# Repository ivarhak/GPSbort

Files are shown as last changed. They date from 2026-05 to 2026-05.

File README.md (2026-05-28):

Hello reader!

This project was made as part of the Hack Club Macondo hardware event. 
The main idea was that I wanted to familiarize myself with design of RF related applications on PCBs.

The board has the following central components: 
NEO-N9M GPS module 
USB Type-C connector 
MT3608 Boost converter 
ESP32-C3-WROOM 
2 SMA jacks for antennas (LORA and GPS) 
AMS1117-3.3 LDO 
DL-RFM95 LORA transceiver

These components allow the board to recieve its GPS position, do some computation then transmit using built in wifi or bluetooth or even using LORA signal up to 5km!
Useful in scenarios like a missing hiker who needs to tell others where they are, or if you have a rocket thats drifted out of your predicted landing zone and you need to find it.

Screenshot 2026-05-27 at 4 51 59 PM
Screenshot 2026-05-27 at 4 51 49 PM
Screenshot 2026-05-27 at 4 51 35 PM

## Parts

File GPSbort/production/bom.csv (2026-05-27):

Designator | Footprint | Quantity | Value | LCSC Part #
_5, _4, _3, _2, |  | 5
BAT1 | BAT-TH_2P-P14.50_2462 | 1 | 2462 | C3029547
C1, C3, C4 | 1206 | 3 | 22uF
C2, C5, C6, C8, C9 | 1206 | 5 | 10uF
C7 | 1206 | 1 | 0.1uF
D1 | 1206 | 1 | D
L1 | 1206 | 1 | 4.7 uH
R1 | 1206 | 1 | 100K
R2 | 1206 | 1 | 15K
R3 | 1206 | 1 | 1M
R4, R5 | 1206 | 2 | 10K
R6, R7, R9 | 1206 | 3 | 5.1K
R8 | 1206 | 1 | 4.7K
RF1, RF2 | SMA-TH_SMA-KWE902 | 2 | SMA-KWE902 | C914554
SW1 | KEY-SMD_L4.0-W3.0-LS4.9-1 | 1 | HX 3X4X2-2P-1.6N TACTILE SWITCH | C49234124
U1 | GPSM-SMD_24P-L16.0-W12.2-P1.10-BL | 1 | NEO-M9N-00B | C5119087
U2 | BULETM-SMD_ESPRESSIF_ESP32-C3-WROOM-02-N4-4MB | 1 | ESP32-C3-WROOM-02-N4 | C2934560
U3 | LCC-16_L16.0-W16.0-P2.00-TL | 1 | DL-RFM95-915M | C2844473
U4 | SOT-23-6_L2.9-W1.6-P0.95-LS2.8-BL | 1 | MT3608 | C84817
U5 | SOT-223-3_L6.5-W3.4-P2.30-LS7.0-BR | 1 | AMS1117-3.3 | C6186
USB1 | USB-C-SMD_TYPE-C-6PIN-2MD-073 | 1 | TYPE-C 16PIN 2MD(073) | C2765186

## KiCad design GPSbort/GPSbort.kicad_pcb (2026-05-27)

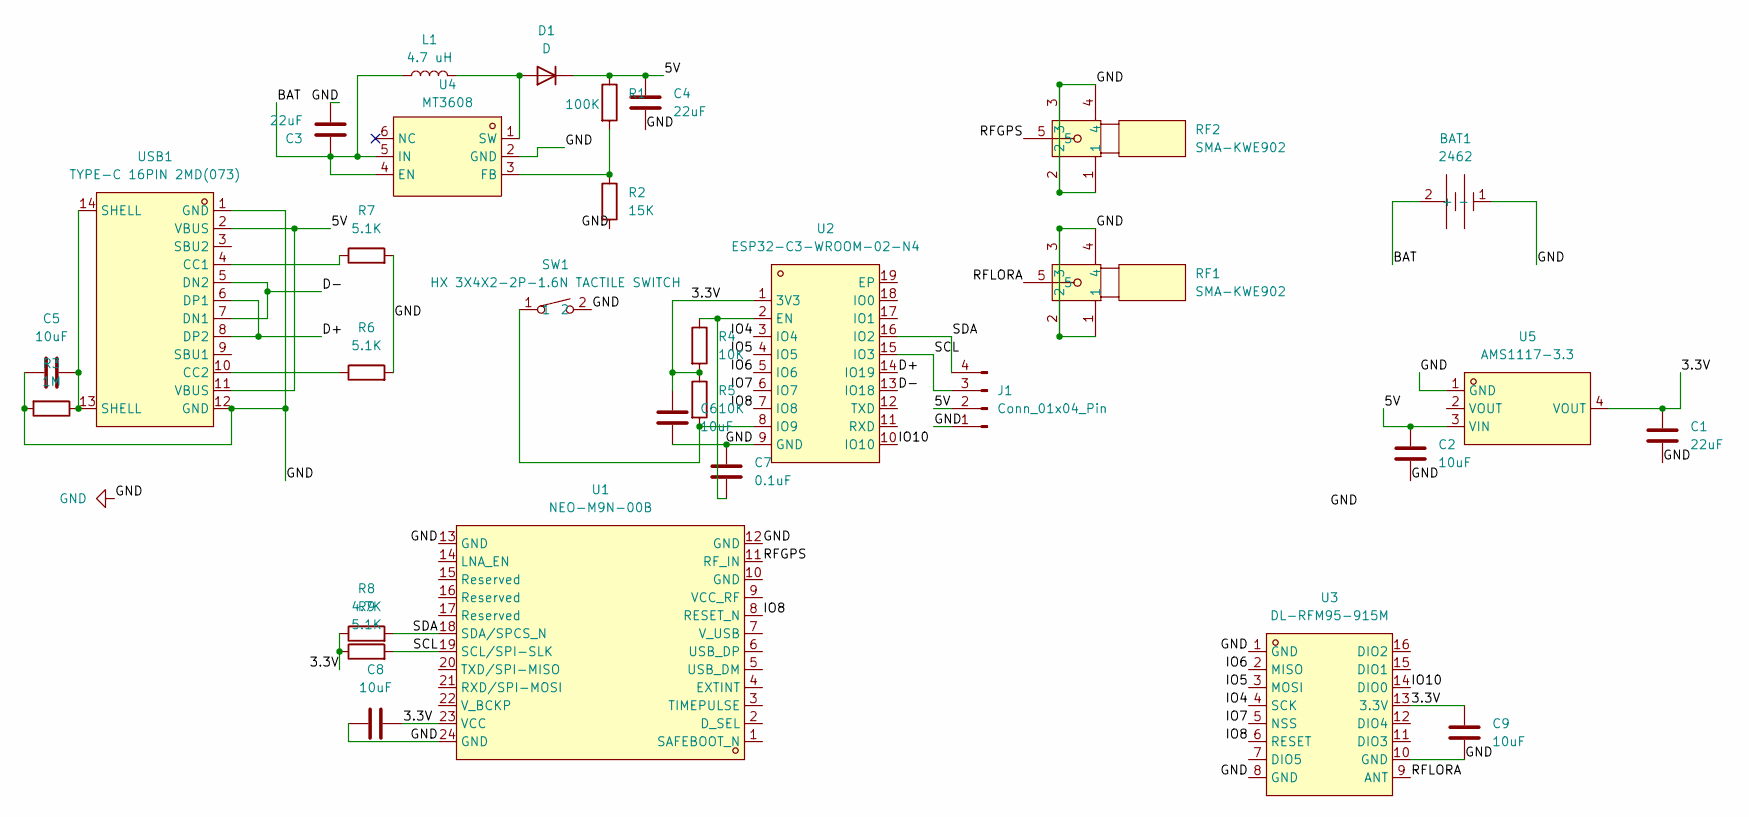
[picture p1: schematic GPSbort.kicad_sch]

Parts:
BAT1: 2462; BAT-TH_2P-P14.50_2462; MPN 2462; LCSC Part C3029547
C1, C3, C4: 22uF; C_1206_3216Metric
C2, C5, C6, C8, C9: 10uF; C_1206_3216Metric
C7: 0.1uF; C_1206_3216Metric
D1: D; D_1206_3216Metric
J1: Conn_01x04_Pin; PinHeader_1x04_P2.54mm_Vertical
L1: 4.7 uH; L_1206_3216Metric
R1: 100K; R_1206_3216Metric
R2: 15K; R_1206_3216Metric
R3: 1M; R_1206_3216Metric
R4, R5: 10K; R_1206_3216Metric
R6, R7, R9: 5.1K; R_1206_3216Metric
R8: 4.7K; R_1206_3216Metric
RF1, RF2: SMA-KWE902; SMA-TH_SMA-KWE902; LCSC Part C914554
SW1: HX 3X4X2-2P-1.6N TACTILE SWITCH; KEY-SMD_L4.0-W3.0-LS4.9-1; LCSC Part C49234124
U1: NEO-M9N-00B; GPSM-SMD_24P-L16.0-W12.2-P1.10-BL; MPN NEO-M9N-00B; LCSC Part C5119087
U2: ESP32-C3-WROOM-02-N4; BULETM-SMD_ESPRESSIF_ESP32-C3-WROOM-02-N4-4MB; MPN ESP32-C3-WROOM-02-N4; LCSC Part C2934560
U3: DL-RFM95-915M; LCC-16_L16.0-W16.0-P2.00-TL; MPN DL-RFM95-915M; LCSC Part C2844473
U4: MT3608; SOT-23-6_L2.9-W1.6-P0.95-LS2.8-BL; MPN MT3608; LCSC Part C84817
U5: AMS1117-3.3; SOT-223-3_L6.5-W3.4-P2.30-LS7.0-BR; MPN AMS1117-3.3; LCSC Part C6186
USB1: TYPE-C 16PIN 2MD(073); USB-C-SMD_TYPE-C-6PIN-2MD-073; LCSC Part C2765186

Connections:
/3.3V: C1.1, C6.1, C8.1, C9.1, R4.2, R5.1, R8.1, R9.1, U1.23 (VCC), U2.1 (3V3), U3.13 (3.3V), U5.4 (VOUT)
/5V: C2.1, C4.1, D1.1 (K), J1.2, R1.1, U5.3 (VIN), USB1.2 (VBUS), USB1.11 (VBUS)
/BAT: BAT1.2 (+), C3.1, L1.1, U4.4 (EN), U4.5 (IN)
/D+: U2.14 (IO19), USB1.6 (DP1), USB1.8 (DP2)
/D-: U2.13 (IO18), USB1.5 (DN2), USB1.7 (DN1)
/IO4: U2.3 (IO4), U3.4 (SCK)
/IO5: U2.4 (IO5), U3.3 (MOSI)
/IO6: U2.5 (IO6), U3.2 (MISO)
/IO7: U2.6 (IO7), U3.5 (NSS)
/IO8: U1.8 (RESET_N), U2.7 (IO8), U3.6 (RESET)
/IO10: U2.10 (IO10), U3.14 (DIO0)
/RFGPS: RF2.5, U1.11 (RF_IN)
/RFLORA: RF1.5, U3.9 (ANT)
/SCL: J1.3, R9.2, U1.19 (SCL/SPI-SLK), U2.15 (IO3)
/SDA: J1.4, R8.2, U1.18 (SDA/SPCS_N), U2.16 (IO2)
GND: BAT1.1 (-), C1.2, C2.2, C3.2, C4.2, C5.1, C6.2, C7.1, C8.2, C9.2, J1.1, R2.2, R3.2, R6.2, R7.2, RF1.1, RF1.2, RF1.3, RF1.4, RF2.1, RF2.2, RF2.3, RF2.4, SW1.2, U1.12 (GND), U1.13 (GND), U1.24 (GND), U2.9 (GND), U3.1 (GND), U3.8 (GND), U3.10 (GND), U4.2 (GND), U5.1 (GND), USB1.1 (GND), USB1.12 (GND)
unnamed: C5.2, R3.1, USB1.13 (SHELL), USB1.14 (SHELL)
unnamed: D1.2 (A), L1.2, U4.1 (SW)
unnamed: C7.2, R4.1, U2.2 (EN)
unnamed: R5.2, SW1.1, U2.8 (IO9)
unnamed: R1.2, R2.1, U4.3 (FB)
unnamed: R7.1, USB1.4 (CC1)
unnamed: R6.1, USB1.10 (CC2)

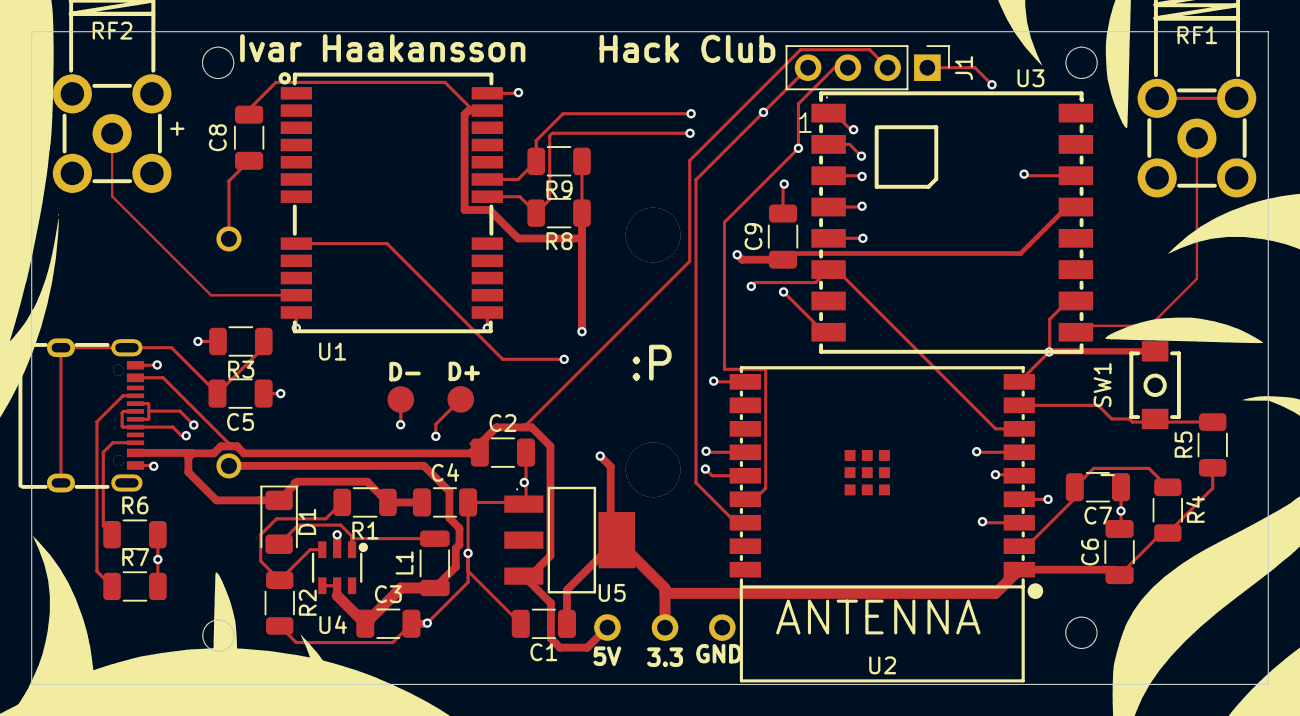
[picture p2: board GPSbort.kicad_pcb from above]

Board: 4 copper layers, 79.0 x 41.7 mm, 31 parts (1 on the bottom side), 23 nets.
